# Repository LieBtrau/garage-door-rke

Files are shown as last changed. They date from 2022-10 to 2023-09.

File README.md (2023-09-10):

# garage-door-rke
Remote keyless entry for garage door

## Problem
1. The Hörmann HS 5 868-BS remote is too heavy.
2. When you forget the remote, you can't open the garage door from the outside.

## Solution

### Hardware
Design files in [EasyEDA](https://oshwlab.com/liebtrau/garage-door-rke)

#### Remote
A light-weight remote has been developed.  It contains :
1. An RFM95W-868S2 LoRa transceiver : set to minimal TX-power, uses very little current.
2. ESP-C3-13U-4M module : available and easy to solder, and includes wifi (not used on the remote).

#### Controller
The controller is mounted near the Hörmann garage door controller, inside the garage.  It consists of:
1. The same PCB transceiver as in the remote (RFM95 + ESP-C3).  So that design only needed to be done once.
2. A 24V to 5V power PCB.  This PCB has an over-sized power supply so that it can also be used in other projects, e.g. for powering a Raspberry Pi.
  * This design was more of an exercise in power supply design than being really practical.
  * Much smaller supplies exist (TPSM84209).
  * If you're after the least effort, then use an 7805 or one of its switching drop-in replacements.
3. A wifi-antenna, connected to the ESP-C3-13U-4M module.

The controller is mounted near the opening of the garage door to increase wireless range.  A 3m UTP-cable connects to an RJ45-terminal socket adapter from [Adafruit](https://www.adafruit.com/product/4981) or [AliExpress](https://www.aliexpress.com/item/1005001493014437.html), which makes connection to the terminal blocks of the Hörmann garage door interface.

### Software

#### LoRa - Authentication

Authentication is based on [Kryptoknight](https://github.com/LieBtrau/arduino-kryptoknight) which is based on a shared secret key between both parties.  It's a light-weight protocol that could also be used on 8-bit MCUs.
This protocol is not vulnerable to rolljam attacks, which is a problem in [rolling code](https://en.wikipedia.org/wiki/Rolling_code) schemes commonly used for this application.

#### WiFi

The controller also includes a web-interface.  By browsing to its fixed local IP-address, a webpage on your smartphone opens.  If you type the correct pin code, the garage door will open.
Security of this web-interface relies on the secrecy of your wifi password and the secret pin.

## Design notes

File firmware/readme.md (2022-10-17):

# Features
* Remote and controller share the same firmware.  Differentiation is done based on compile time parameter and #define structure.

# Library for wireless module
* [RadioLib](https://github.com/jgromes/RadioLib/wiki)
    * Support for some ham-radio protocols like AX.25
    * Limited higher layer2 support (no encapsulation of packets into frames, no flow control, no retransmissions)
* [Arduino-LoRa](https://github.com/sandeepmistry/arduino-LoRa)
    * It inherits from the Stream class, which will make it easier to interface it to other libraries such as [PacketIO](https://packetio.readthedocs.io/en/latest/).
* [RadioHead](http://www.airspayce.com/mikem/arduino/RadioHead/)
    * Supports acknowledgements on frames and re-transmissions, but no support for encapsulation of packets into frames.  The application has to split packets into frames and make sure these arrive.
    * SX1278 : no FSK support, only LoRa.
    * I refuse to add more modules to this library, as Mike McMauley heavily based his MRF89XA driver [on my code](https://github.com/LieBtrau/RadioHead/blob/010059f01bc5f790ef788f355999595e51d3f9b8/RH_MRF89XA.cpp) without owing me credit for it.  Removing a copyright notice in a source code file is not a nice thing to do.
    * If you're not using the default SPI-pins, you'll have to patch RHHardwareSpi.cpp
* [LowPowerLab](https://github.com/LowPowerLab/RFM69)
    * RFM69/SX1231 only
    * OSI-layer2 support thrown together with hardware driver.  This would take some time to separate that nicely.

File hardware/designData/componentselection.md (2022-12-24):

# MCU

## STM32WLE5WJC (includes LoRa radio)

### Modules
* [RAK3172](https://store.rakwireless.com/products/wisduo-lpwan-module-rak3172?variant=40014759297222)
* [Seeed Wio-E5 STM32WLE5JC Module](https://wiki.seeedstudio.com/LoRa-E5_STM32WLE5JC_Module/)

### Firmware development
* no support for PlatformIO yet
* [LoRa-E5-mini](https://revspace.nl/LoRa-E5-mini) : Arduino toolchain

## ESP32-C3
* cheap
* low power
* available in stock
* PlatformIO support

### Modules
* [Lolin C3-MINI](https://www.wemos.cc/en/latest/c3/c3_mini.html) : 
    * default SPI pins (GPIO14-17) are not connected.
    * WiFi doesn't work (LDO too weak?)
* ESP32-C3-WROOM-02U-N4
    * Small
    * available
    * cheap
    * powerful enough
    * low power
    
## Seeeduino XIAO
* PlatformIO support
* internal 3V3 not sufficient to power RFM69HW.  So there's no more point in using the Xiao.  If an external 3V3 LDO is needed, I might as well use a cheaper and smaller ESP32-C3 module.  The ESP32-C3 might serve me better in the future as well, as it has bluetooth and wifi.

## ATmega328
* PlatformIO support

### 328Board 
* [link1](https://www.tindie.com/products/kdcircuits/328-board-atmega328p-breakout/)
* [link2](https://www.kevindarrah.com/wiki/index.php?title=328Board)

### bare atmega328pb
* not available anywhere
 
# Radio

## Frequency : 868MHz
Smaller antennas than 433MHz, better building penetration than 2.4GHz.  Deployment in EU, so no 915MHz.
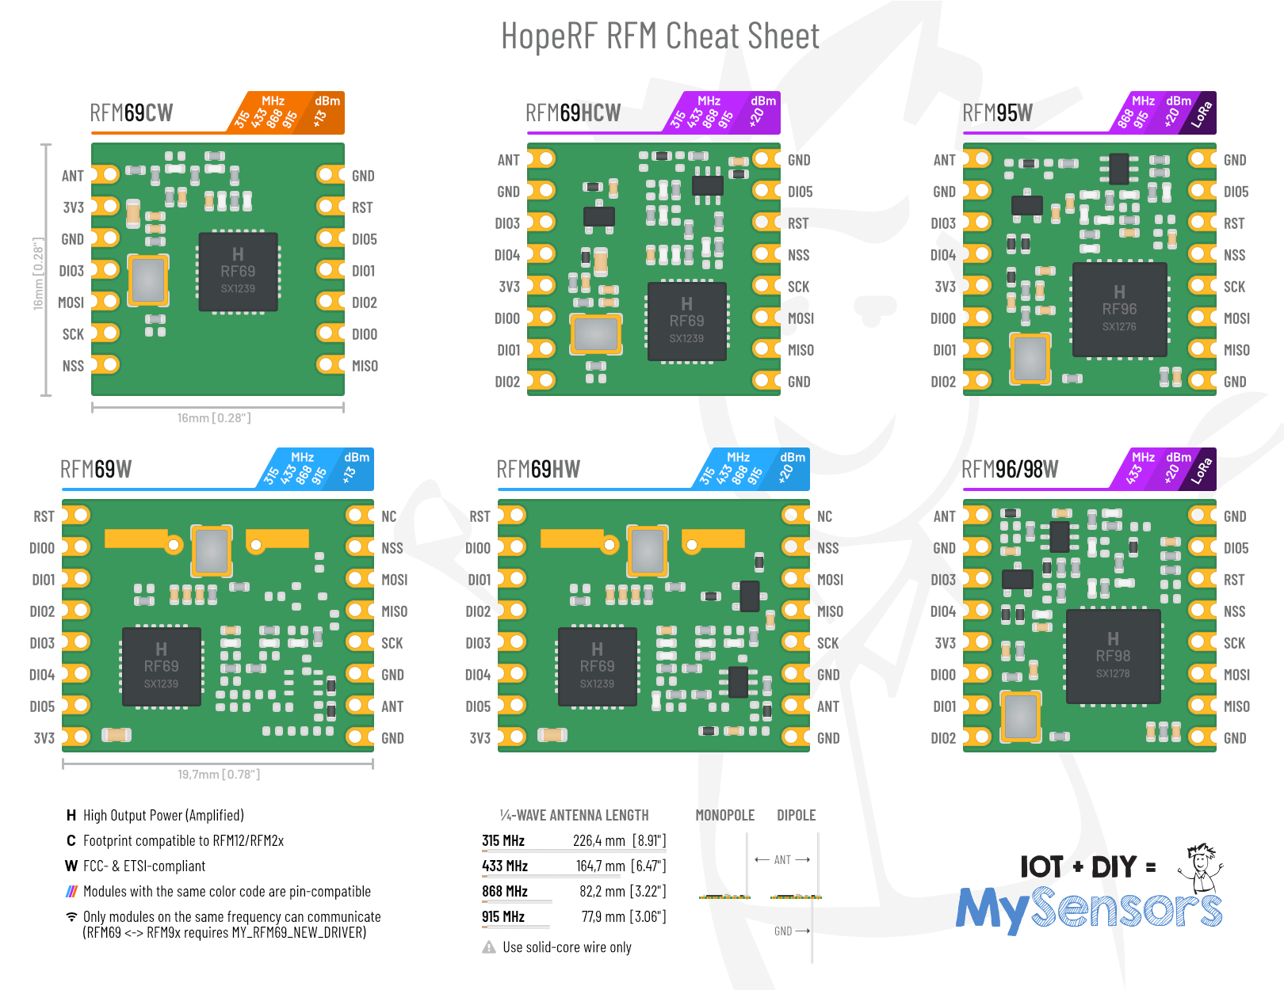
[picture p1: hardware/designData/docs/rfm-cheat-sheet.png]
HopeRF modules versions

Due to limited space, we'll use the smaller modules : 
* RFM69HCW-868S2 (limited availability)
* RFM95W-868S2 (available at Antratek)

## RFM69HW (used for testing)
* rebranded SX1231 radio
* cheaper than LoRa variant
* Be careful about these HopeRF modules.  There are wide and narrow parts.  The RFM69HW is a wide part.
* RST must be kept low (unconnected at module)
* at least 22uF buffer capacitor is needed on 3V3

# Housing
Ingun needle box.
Internal height = 9mm

## Bottom side
* Li-Ion : 4.7mm high
* JST PH SM4 : 5.5mm high (can be removed)

## PCB
* 1.6mm thick -> can be as low as 0.6mm

## top side

### Push button
* On R1: PTS645SK50SMTR92LFS : 3.75mm high, top is 5mm high, which is at least 1.5mm too low to push in.
* On R2 : 
 * Total height should be around 7mm.  That's perfect height for covering switch with a PCB as front panel.  See [bobricius design's](https://hackaday.io/project/171790/components)
 * Height of the switch housing is limited due to the existing box:
  * CUI TS04 : 3.5mm + height of studs (unknown)
  * E-switch TL3305 : height not defined
  * E-switch TL3301 : 4.0mm
  * C&K PTS647 : 3.2mm high, 4.5 x 4.5 mm footprint
  * *C&K PTS645 PTS645SK70SMTR92LFS (=260gf)*, PTS645SL70SMTR92LFS (=130gf) : 3.75mm
  * Schurter LSG : 3.9mm high
  * APEM ADTSM : 4.1mm
  * APEM MJTP : 4.0mm
  * Wuerth WS-TASV : 3.4mm + undefined studs height

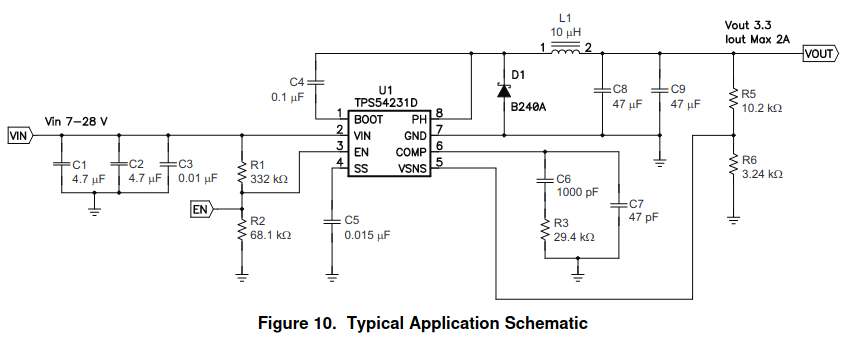
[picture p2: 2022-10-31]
hardware/designData/docs/fig10.png

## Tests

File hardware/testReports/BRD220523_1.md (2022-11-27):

# Overview

TBD : list with links of tests

ToC

# Test Summary

## Equipment

| Equipment | Description | Serial Number | Date of last calibration |
|--|--|--|--|
| Siglent SPD3303C| Labo DC Power supply| SPD3EEEC6R0513| 2022-03-06 |
| Siglent SDL1020X-E| DC Electronic Load | SDL13GCC6R0182| 2022-02-11|
| Mastech M92 | digital multimeter | 20011206033 | (?) |
## DuT

| PCB number | Revision | Serial Number | Firmware version |
|--|--|--|--|
| BRD220523 | 1.0 | | |

## Test incident reports
### TIR1
* Problem: Power supply doesn't start because the load is so high that it prevents the output voltage from rising.
* Action: Add an output switch which only connects the PSU to the load once the output voltage is high enough.
### TIR2
* Problem: Input filtering likely to be inadequate
* Action: Add two sections of 10µH/10µF
# Test procedures 

## Buck converter from 24V to 5V
### Test setup
1. Connect labo power supply on CN7
2. Connect electronic load on CN6, set to CC-mode
### Test steps
| Action | Expected Result | Observed result | Status |
|--|--|--|--|
| Input voltage UVLO (rising) with 500mA load | 5.3 to 5.5V | 5.80Vin, Vout = 4.46V | *Acceptable* |
| Input voltage UVLO (falling) with 500mA load | 300mV hysteresis | 5.47Vin| *OK* |
| Output voltage ramp up<br/>Vin=24V, Load=500mA | Voltage ramps up linearly<br/>no hick-ups | * In CC-mode, max. current <5mA for successful power up.<br/>* In CR-mode, R must be ≥6Ω <br/>Rising Vout and switching node | [TIR1](#tir1)| 
| Output voltage ramp down<br/>Vin=24V, Load=500mA |Voltage ramps down linearly<br/>no hick-ups | Voltage ramps down to 0V in 20ms | *OK* |
| Oscillation frequency | 
| Efficiency |
| Line regulation |
| Load regulation |
| Load Transient response |

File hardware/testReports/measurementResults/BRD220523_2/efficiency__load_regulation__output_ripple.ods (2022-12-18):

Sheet: 24Vin
Load current | Vpp-ripple output | Vaverage | Load regulation | Vin | Iin | Efficiency | Vpp ripple input
[A] | [mV] | [V] | [%] | [V] | [A] | [%] | [mV]
0 | 9.95 | 5.0248 | 0.495999999999999 | 24 | 0 | #DIV/0!
0.025 | 8.64 | 5.025 | 0.500000000000007 | 24 | 0.01 | 52.34375 | 8.55
0.05 | 8.12 | 5.024 | 0.48 | 24 | 0.02 | 52.3333333333333 | 7.37
0.1 | 8.86 | 5.023 | 0.459999999999994 | 24 | 0.03 | 69.7638888888889 | 7.2
0.2 | 9.59 | 5.022 | 0.440000000000005 | 24 | 0.05 | 83.7 | 9.53
0.4 | 10.09 | 5.02 | 0.399999999999992 | 24 | 0.1 | 83.6666666666667 | 13.38
0.6 | 10.79 | 5.018 | 0.359999999999996 | 24 | 0.15 | 83.6333333333333 | 15.49
0.8 | 11.4 | 5.016 | 0.32 | 24 | 0.2 | 83.6 | 16.99
1 | 11.65 | 5.014 | 0.280000000000005 | 24 | 0.25 | 83.5666666666667 | 17.84
1.2 | 11.95 | 5.012 | 0.239999999999991 | 24 | 0.3 | 83.5333333333333 | 18.2
1.4 | 12.08 | 5.01 | 0.199999999999996 | 24 | 0.35 | 83.5 | 18.49
1.6 | 12.37 | 5.008 | 0.16 | 24 | 0.4 | 83.4666666666667 | 18.55
1.8 | 12.75 | 5.006 | 0.120000000000005 | 24 | 0.45 | 83.4333333333333 | 18.52
2 | 13.76 | 5.003 | 0.0600000000000023 | 24 | 0.5 | 83.3833333333333 | 18.4
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

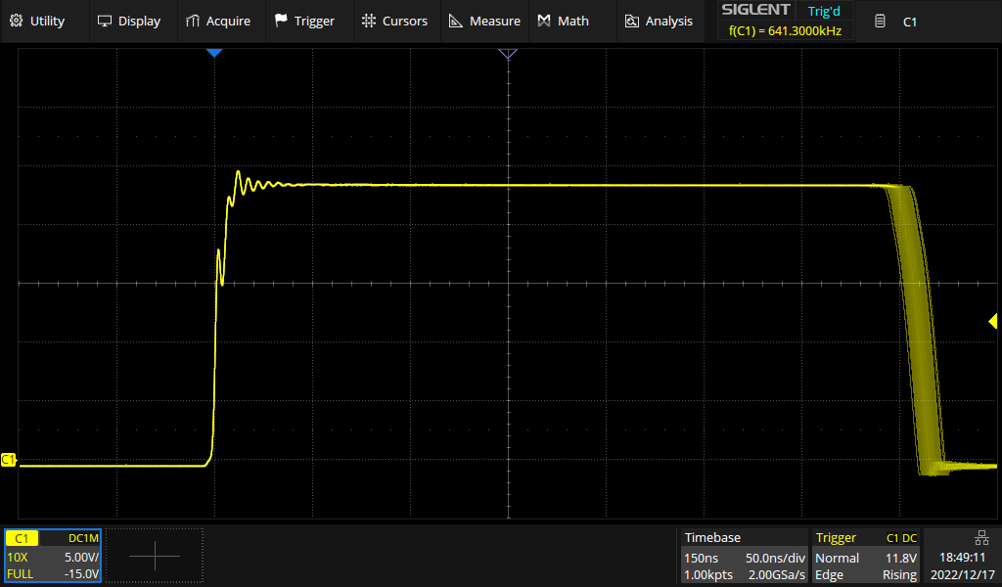
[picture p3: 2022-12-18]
hardware/testReports/measurementResults/BRD220523_2/switching_node_B350A.png

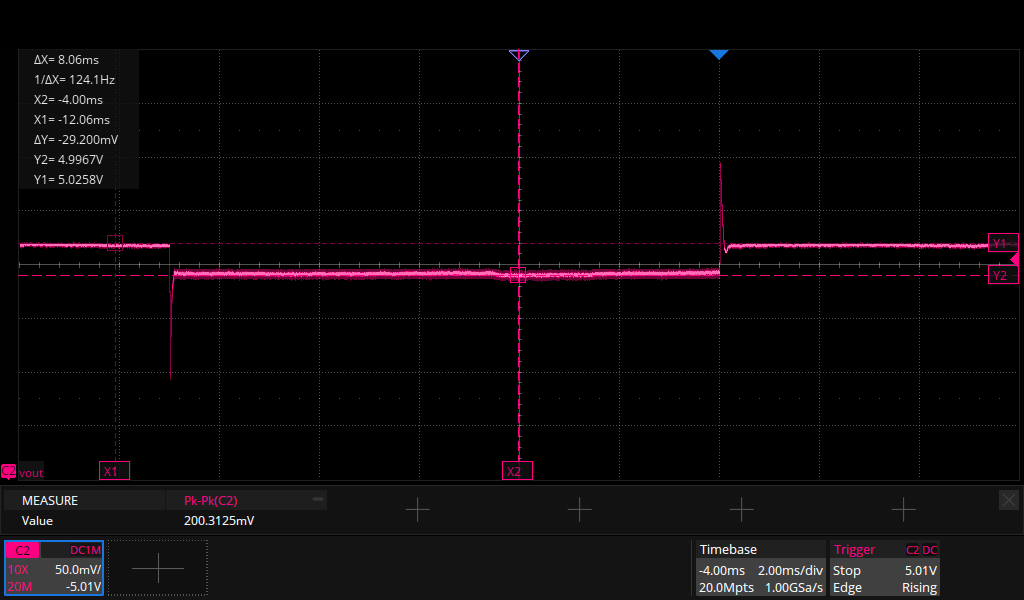
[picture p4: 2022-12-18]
hardware/testReports/measurementResults/BRD220523_2/Load_transient_200mA_2A.png

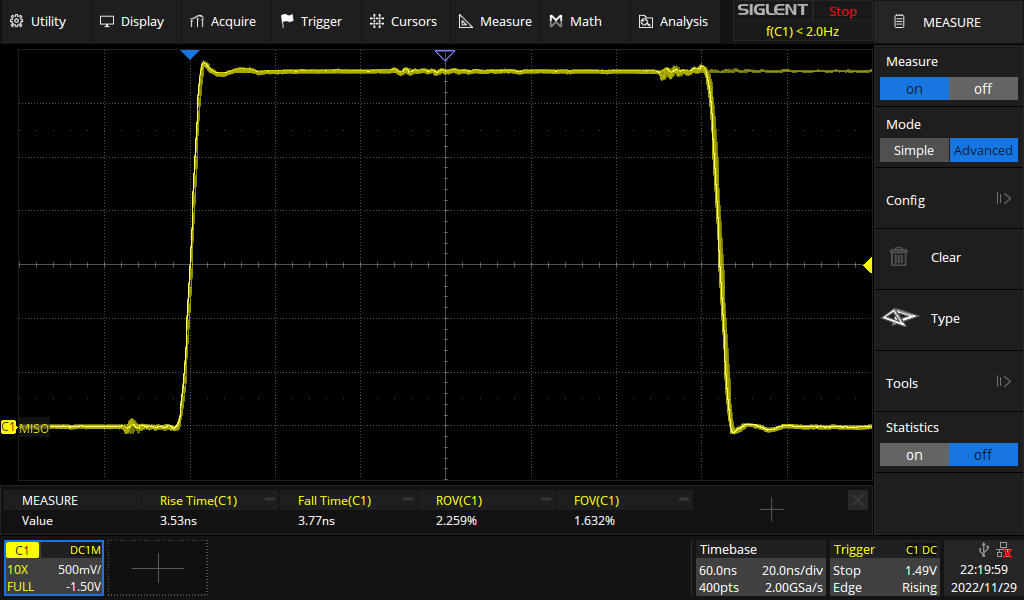
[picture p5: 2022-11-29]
hardware/testReports/measurementResults/BRD220522_2/SPI/MISO.png

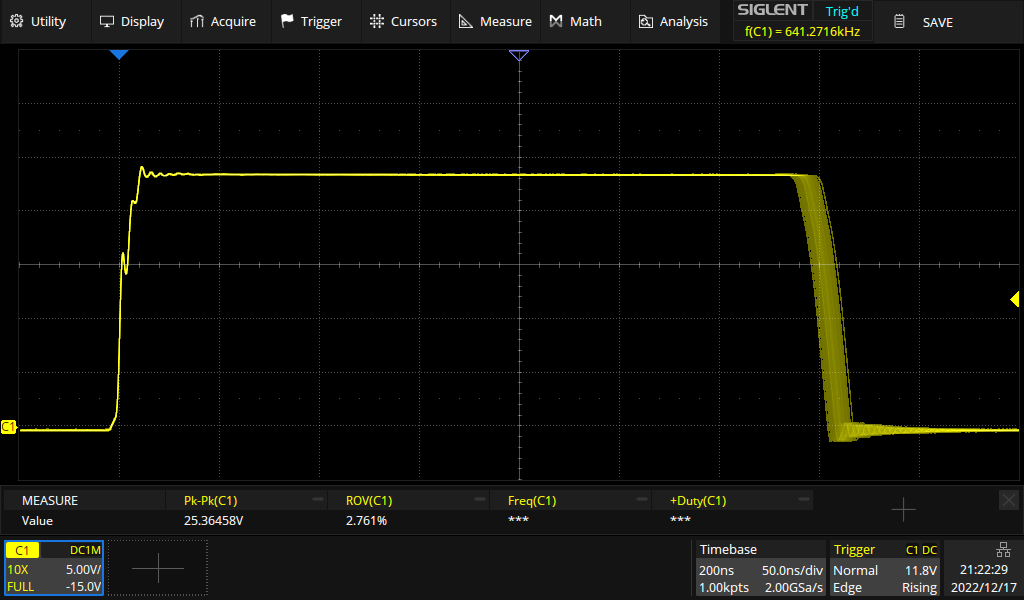
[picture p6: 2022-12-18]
hardware/testReports/measurementResults/BRD220523_2/switching_node_b340af-13.png

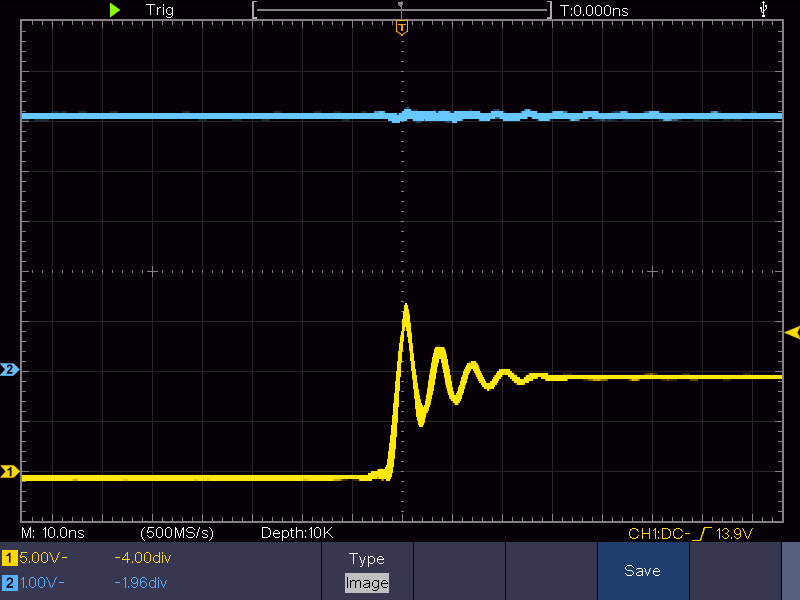
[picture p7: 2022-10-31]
hardware/testReports/measurementResults/BRD220523_1/10Vin_1Aout_10ohm_in_series_with_C11.png

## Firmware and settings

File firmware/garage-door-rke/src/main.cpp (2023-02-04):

/*
  Adaptation of example created by Tom Igoe, created 28 April 2017
*/
#include <SPI.h> // include libraries
#include "pins.h"
#include "AsyncDelay.h"

static const char* TAG = "Main";
extern "C"
{
#include "bootloader_random.h"
}
#include "constants.h"

void sendMessage(String outgoing);
void onReceive(int packetSize);

bool radioTx(byte *packet, byte packetlength)
{
  ESP_LOGI(TAG, "Device sends %dbytes.\r\n", packetlength);
#if LOG_LOCAL_LEVEL == ESP_LOG_VERBOSE
  showArray(packet, packetlength);
#endif
  LoRa.beginPacket();
  LoRa.write(packet, packetlength);
  LoRa.endPacket();
  return true;
}

void showArray(byte *data, byte len)
{
  for (int i = 0; i < len; i++)
  {
    Serial.printf("%02x ", data[i]);
    if ((i + 1) % 24 == 0)
    {
      Serial.println();
    }
  }
  Serial.println();
}

void setup()
{
  esp_log_level_set("*", ESP_LOG_DEBUG);
  presetup();
  
  // Init serial port
  Serial.begin(115200);
  while (!Serial)
    ;
  ESP_LOGD(TAG, "\r\nBuild %s\r\n", __TIMESTAMP__);

  // Init LoRa
  LoRa.setPins(pinnCS, pinRST_RADIO, pinDIO0, pinSCK, pinMOSI, pinMISO);
  if (!LoRa.begin(868E6))
  {
    while (true)
    {
      ESP_LOGE(TAG, "LoRa init failed. Check your connections.");
      delay(1000);
    }
  }
  // Init Kryptoknight
  bootloader_random_enable();
  if (sodium_init() < 0 || !setupKryptoKnight())
  {
    while (true)
    {
      ESP_LOGE(TAG, "Kryptoknight init failed. Check your connections.");
      delay(1000);
    }
  }

  postsetup();

  ESP_LOGI(TAG, "Ready to rumble.");
}

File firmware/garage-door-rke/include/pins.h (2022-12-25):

#pragma once

#if BRD220522_VERSION == 1
//SPI - signals
const int pinSCK = 10;
const int pinMOSI = 7;
const int pinMISO = 8;
const int pinnCS = 6;

//Radio connection 
const int pinDIO0 = 2;
const int pinRST_RADIO = 3;

//ADC-connection
const int pinSampleADC = 1;
const int pinEn_ADC = 0;

const int pinRedLED = 5;    // LoBatt indicator on remote, garage-door pulse on controller
const int pinEn_Pwr = 4;    // Enable power on remote, no function on controller

#elif BRD220522_VERSION == 2
//SPI - signals
const int pinSCK = 7;
const int pinMOSI = 0;
const int pinMISO = 1;
const int pinnCS = 2;

//Radio connection 
const int pinDIO0 = 6;
const int pinRST_RADIO = 8;

//ADC-connection
const int pinSampleADC = 3;
const int pinEn_ADC = 10;

const int pinRedLED = 4;    // LoBatt indicator on remote, garage-door pulse on controller
const int pinEn_Pwr = 5;

#else
#error "No pin definitions defined"
#endif

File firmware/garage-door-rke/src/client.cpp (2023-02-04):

#include "constants.h"
#include "pins.h"
#include "secretKey.h"

static const char* TAG = "Client";

#if REMOTE == 1
#include "KryptoknightClient.h"
#include "esp_adc_cal.h"

static const ClientRecord myID = {0x002ba78c, SECRET_KEY};
static KryptoknightClient client_2pap(myID.client_id, (byte *)myID.shared_secret_key, SERVER_ID);
static AsyncDelay timerStartAuthentication;
static esp_adc_cal_characteristics_t adc_chars;
static const uint32_t MIN_BAT_VOLTAGE = 3600; //[mV]

static uint8_t buf[BUFF_SIZE];

void authenticationOkAction()
{
    // for (int i = 0; i < 3; i++)
    // {
    //     digitalWrite(pinRST_RADIO, LOW); // Light green LED && reset radio.
    //     delay(150);
    //     digitalWrite(pinRST_RADIO, HIGH);
    //     delay(150);
    // }
}

static void powerOff()
{
    digitalWrite(pinEn_Pwr, LOW);
}

void presetup()
{
    // Make sure this device remains powered
    pinMode(pinEn_Pwr, OUTPUT);
    digitalWrite(pinEn_Pwr, HIGH);

    // Turn red LED off before ADC-measurement
    pinMode(pinRedLED, OUTPUT);
    digitalWrite(pinRedLED, LOW);

    // Enable ADC
    pinMode(pinEn_ADC, OUTPUT);
    digitalWrite(pinEn_ADC, HIGH);
}

void postsetup()
{
    uint32_t voltage;
    const int R5 = 3300;  // ohm
    const int R6 = 10000; // ohm

    LoRa.setTxPower(0);

    // Get ADC-calibration data
    ESP_ERROR_CHECK(esp_adc_cal_check_efuse(ESP_ADC_CAL_VAL_EFUSE_TP));
    esp_adc_cal_characterize(ADC_UNIT_1, ADC_ATTEN_DB_6, ADC_WIDTH_BIT_12, 0, &adc_chars);
    // Configure the ADC with the calibration data
    adc1_config_channel_atten(ADC1_CHANNEL_3, ADC_ATTEN_DB_6);
    // Give voltage some time to stabilize
    delay(25);
    // Do the ADC-measurement
    int voltage_sum = 0;

    // Average the voltage over a number of ADC-samples
    const int SAMPLE_COUNT = 10;
    for (int i = 0; i < SAMPLE_COUNT; i++)
    {
        if (esp_adc_cal_get_voltage(ADC_CHANNEL_3, &adc_chars, &voltage) == ESP_OK)
        {
            voltage_sum += voltage;
        }
    }
    double average = voltage_sum / SAMPLE_COUNT;

    int battery_voltage = average * (R5 + R6) / R5;
    ESP_LOGD(TAG, "sampled battery voltage = %dmV\n", battery_voltage);
    if (battery_voltage < MIN_BAT_VOLTAGE)
    {
        digitalWrite(pinRedLED, HIGH);
    }

    // Disable ADC to save some power
    digitalWrite(pinEn_ADC, LOW);

    // Send authentication request
    client_2pap.startAuthentication();
}

bool setupKryptoKnight()
{
    client_2pap.setTransmitPacketEvent(radioTx);
    timerStartAuthentication.start(2000, AsyncDelay::MILLIS);
    return true;
}

void onReceive(int packetSize)
{
    if (packetSize == 0)
        return; // if there's no packet, return

    if (LoRa.readBytes(buf, min(packetSize, BUFF_SIZE)) == packetSize)
    {
    ESP_LOGI(TAG, "Device sends %dbytes.\r\n", packetSize);
#if LOG_LOCAL_LEVEL == ESP_LOG_VERBOSE
    showArray(buf, packetSize);
#endif
        if (client_2pap.handleIncomingPacket(buf, packetSize))
        {
            ESP_LOGD(TAG, "Authentication successful");
            authenticationOkAction();
            powerOff();
        }
    }
    else
    {
        ESP_LOGE(TAG, "invalid message");
    }
}

void loop()
{
    if (timerStartAuthentication.isExpired())
    {
        powerOff();
    }
    onReceive(LoRa.parsePacket());
}

#endif

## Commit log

2022-04-26 simple ping with RFM69 on ESP32
2022-05-06 Lolin C3-Mini, no default SPI-connected
2022-05-08 Current measurement
2022-05-09 Enable one way authentication to save power
2022-05-18 97% successful authentication * less serial printing * narrow band radio config * mutual authentication
2022-05-20 1-way authentication with short messages
    [main.cpp]
2022-05-29 AnalogRead on ESP32-C3
2022-05-29 Arduino analogRead has too much error.
    [main.cpp]
2022-07-04 Adding PCB-data
    [BRD220522.schdoc, BRD220522_2022-07-04.pcbdoc, BRD220523.schdoc]
2022-10-01 Update to new way to do USB-CDC on ESP32-C3
2022-10-01 Blink LEDs on BRD220522/1
2022-10-02 ADC-calibration cleanup
2022-10-17 Add test of analog in voltage
2022-10-17 Add test of power on/off
2022-10-31 Calculating TPS54231 power supply
2022-11-27 Adding LED example for R2 (with patched LEDs)
2022-11-29 SPI tests done on BRD220522_2
2022-12-04 Using USB-CDC instead of UART connection
2022-12-04 Making sure device remains powered.
2022-12-04 Documenting issues with the board
2022-12-04 UART instead of USB-CDC
2022-12-18 testing BRD220523_2
    [efficiency__load_regulation__output_ripple.ods]
2022-12-24 Updating momentary switch info Test report of BRD220523_2
2022-12-24 webserver for pin form
2022-12-25 Fix ADC sampling
2022-12-27 Adjusting UVLO Garage door only outputs 22.3V
2022-12-27 Minimize TX power consumption + do current consumption measurement
2023-01-21 Garage controller uses R2 PCB
2023-01-25 PCB doesn't fit well in housing
2023-06-03 PCB design R2
    [BRD220522.pcbdoc, BRD220522.schdoc, BRD220522_2022-07-04.pcbdoc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]
2023-06-03 Hardware R3
    [BRD220522.pcbdoc, BRD220522.schdoc, BRD220523.schdoc]
2023-09-10 Update README.md
    Add link to EasyEDA
    Minor upgrade about 24V/5V power supply
